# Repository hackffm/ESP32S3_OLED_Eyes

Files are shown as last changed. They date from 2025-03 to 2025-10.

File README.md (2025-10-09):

# ESP32S3_OLED_Eyes
Touch-sensitive OLED Eyes for ESP32-S3 modules based on playfultechnology / esp32-eyes. A badge from Hackerspace-FFM.de that shows eye animation and name on the OLED display.

This is a picture of the badge: 
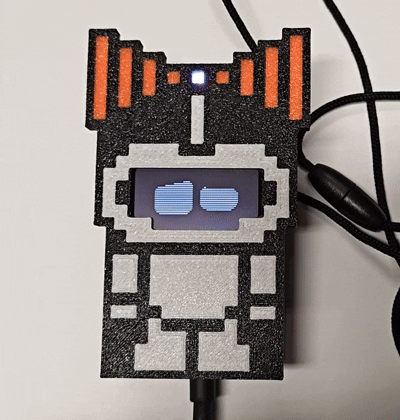
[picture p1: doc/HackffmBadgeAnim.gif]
Badge Animated


More info in [Hackerspace-FFM Wiki](https://www.hackerspace-ffm.de/wiki/index.php?title=Hackerspace-FFM_Badge)

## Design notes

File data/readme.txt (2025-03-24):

This file is in LittleFS of ESP32. More infos about badge:
https://www.hackerspace-ffm.de/wiki/index.php?title=Hackerspace-FFM_Badge

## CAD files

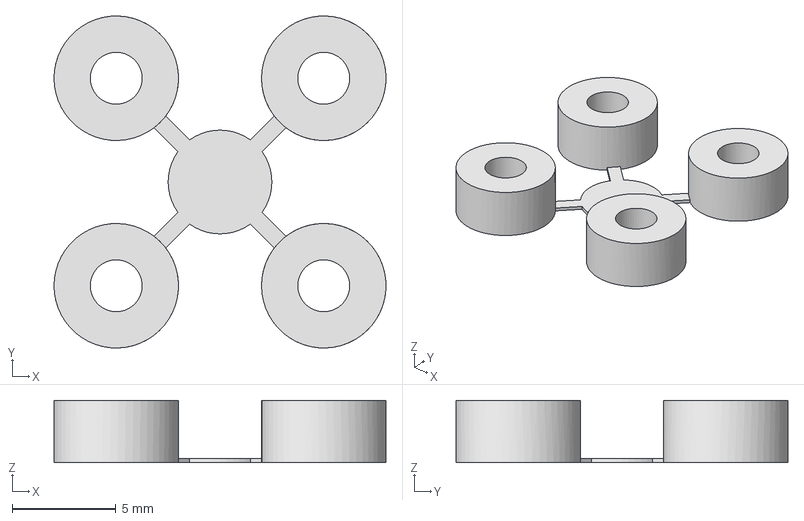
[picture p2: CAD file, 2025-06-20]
hardware/main_mechanics/spacer_3mm.stp
16.0 x 16.0 x 3.00 mm

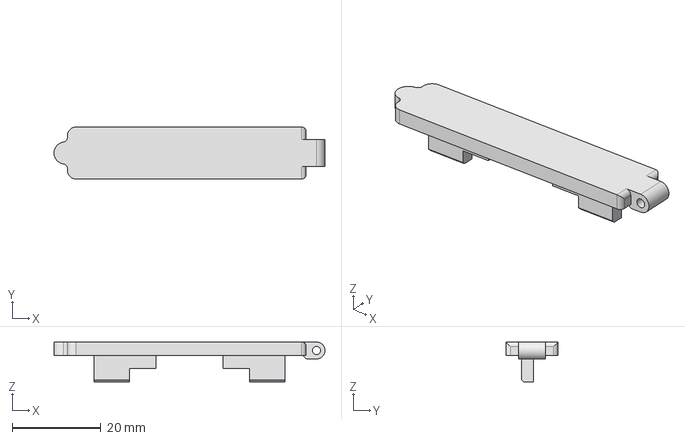
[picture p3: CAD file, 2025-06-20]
hardware/mounting_tools/mcu solder tool lid.stp
61.0 x 11.7 x 9.00 mm

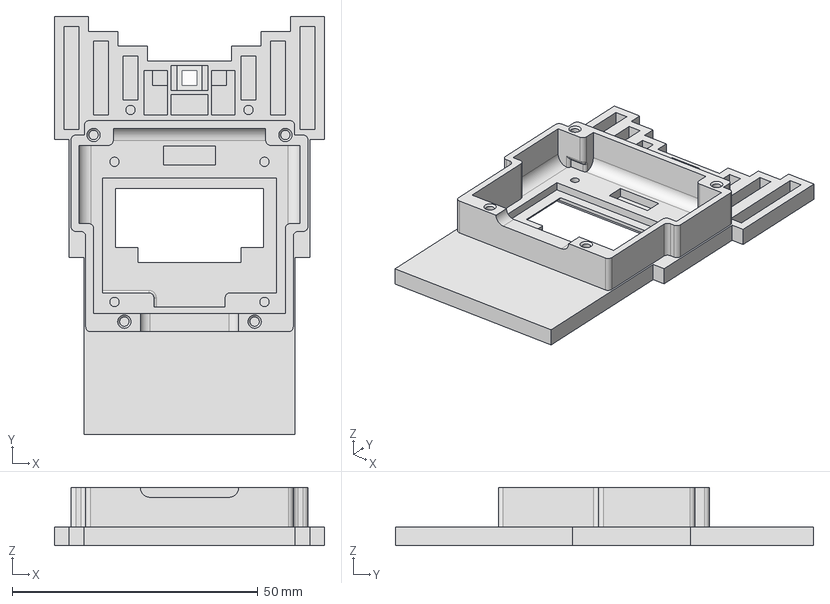
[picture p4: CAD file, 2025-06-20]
hardware/main_mechanics/hackffm-badge.stp
55.0 x 85.0 x 11.8 mm
logo_black
body-new
signal-new
transparent

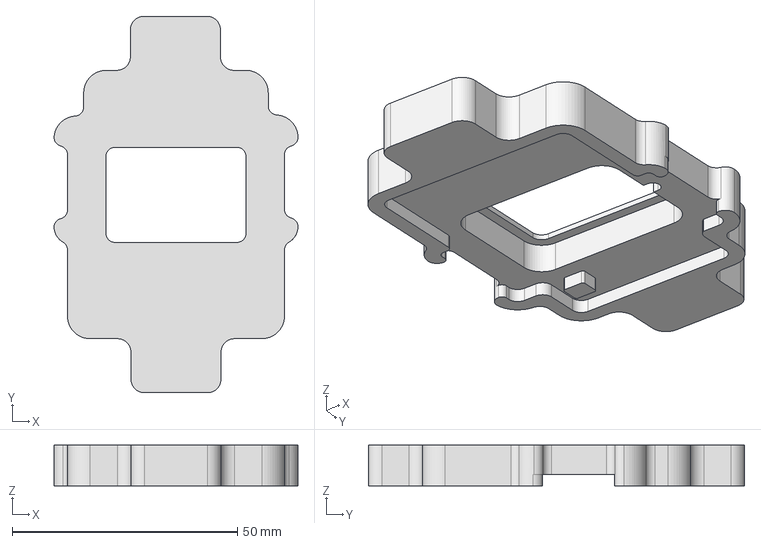
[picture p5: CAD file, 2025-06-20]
hardware/mounting_tools/glue-tool.stp
54.2 x 83.6 x 9.00 mm

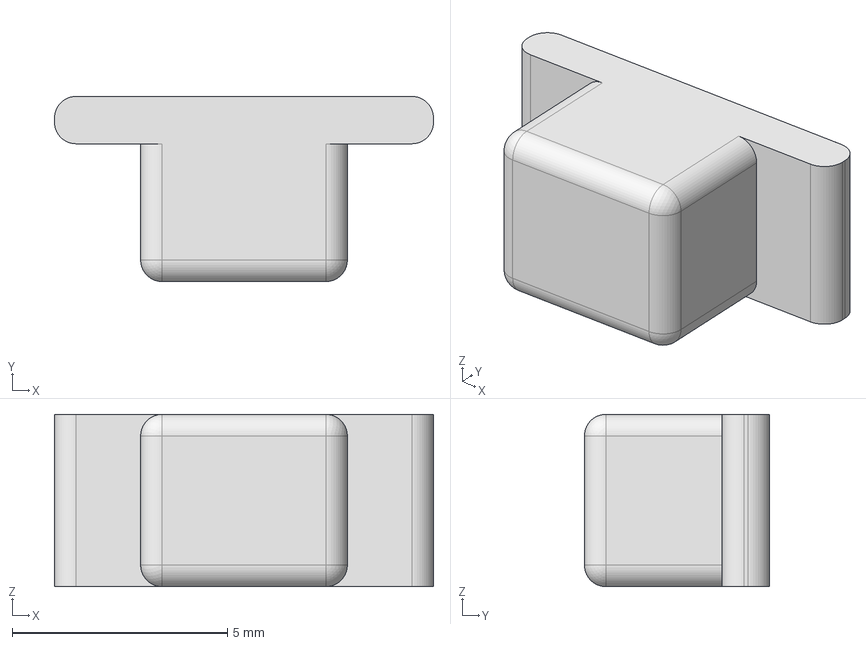
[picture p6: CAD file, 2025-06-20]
hardware/main_mechanics/button-2.stp
8.80 x 4.30 x 4.00 mm

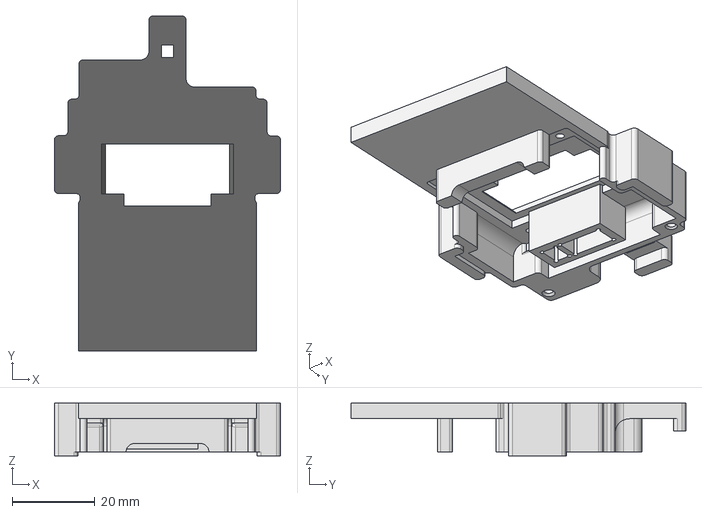
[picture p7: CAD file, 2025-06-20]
hardware/mounting_tools/solder-tool.stp
54.7 x 81.0 x 12.8 mm

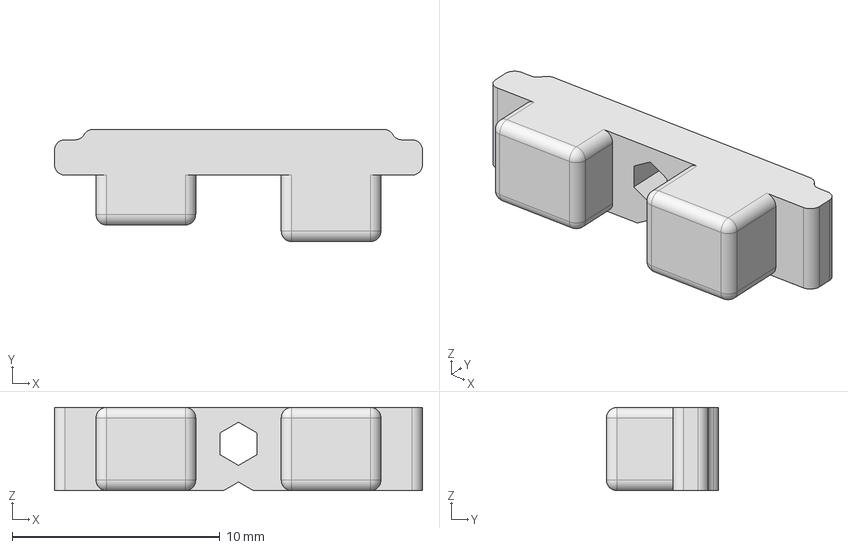
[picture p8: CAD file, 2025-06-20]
hardware/main_mechanics/button.stp
17.7 x 5.40 x 4.00 mm

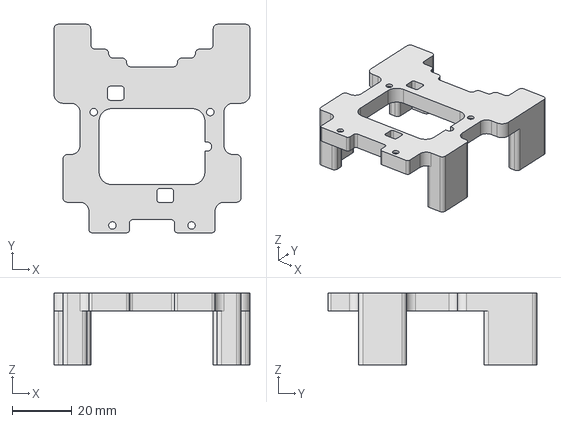
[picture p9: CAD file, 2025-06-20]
hardware/mounting_tools/mounting-tool.stp
65.6 x 69.8 x 24.0 mm

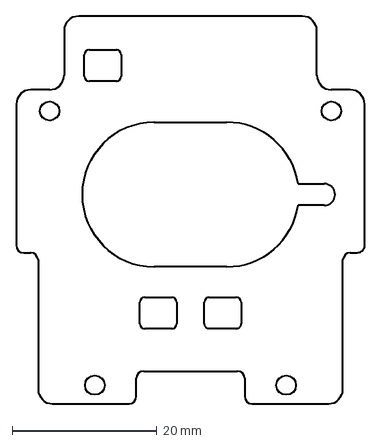
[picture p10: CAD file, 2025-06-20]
hardware/main_mechanics/backside_plexi.dxf
48.2 x 53.6 mm

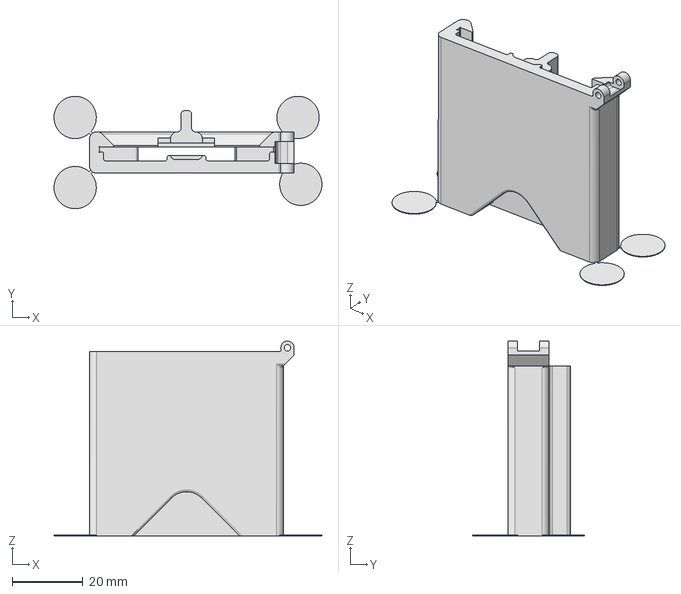
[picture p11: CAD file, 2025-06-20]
hardware/mounting_tools/mcu-solder-tool.stp
76.0 x 31.9 x 55.2 mm

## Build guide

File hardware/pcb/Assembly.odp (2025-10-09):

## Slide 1

1.

Nur bei Audioversion

22k

1uF

R6 wird nicht benötigt

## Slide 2

2.

Digital-transistor

MOSFET P-Ch

Taster

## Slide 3

3.

Nur bei Audioversion

4.7k

1nF

LM4871

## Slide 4

Jumper

Blaues board

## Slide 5

Jumper

Schwarzes board

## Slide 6

Jumper

Schwarzes Board

Jumper

Blaues Board

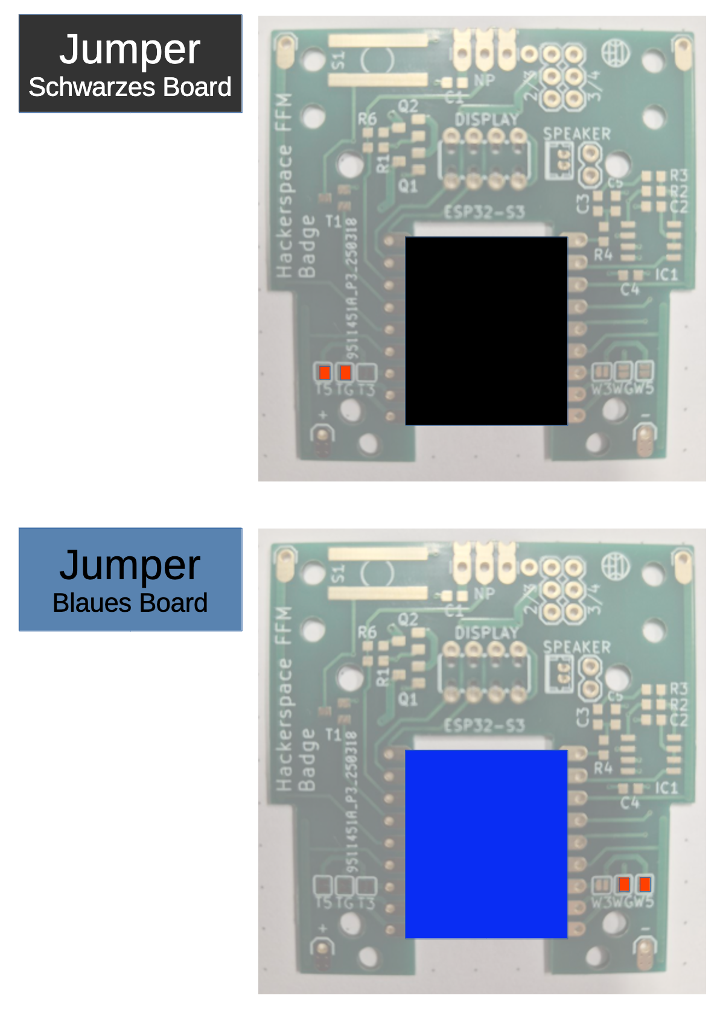
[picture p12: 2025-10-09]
doc/HackFFMEyes Board Jumper Soldering.png

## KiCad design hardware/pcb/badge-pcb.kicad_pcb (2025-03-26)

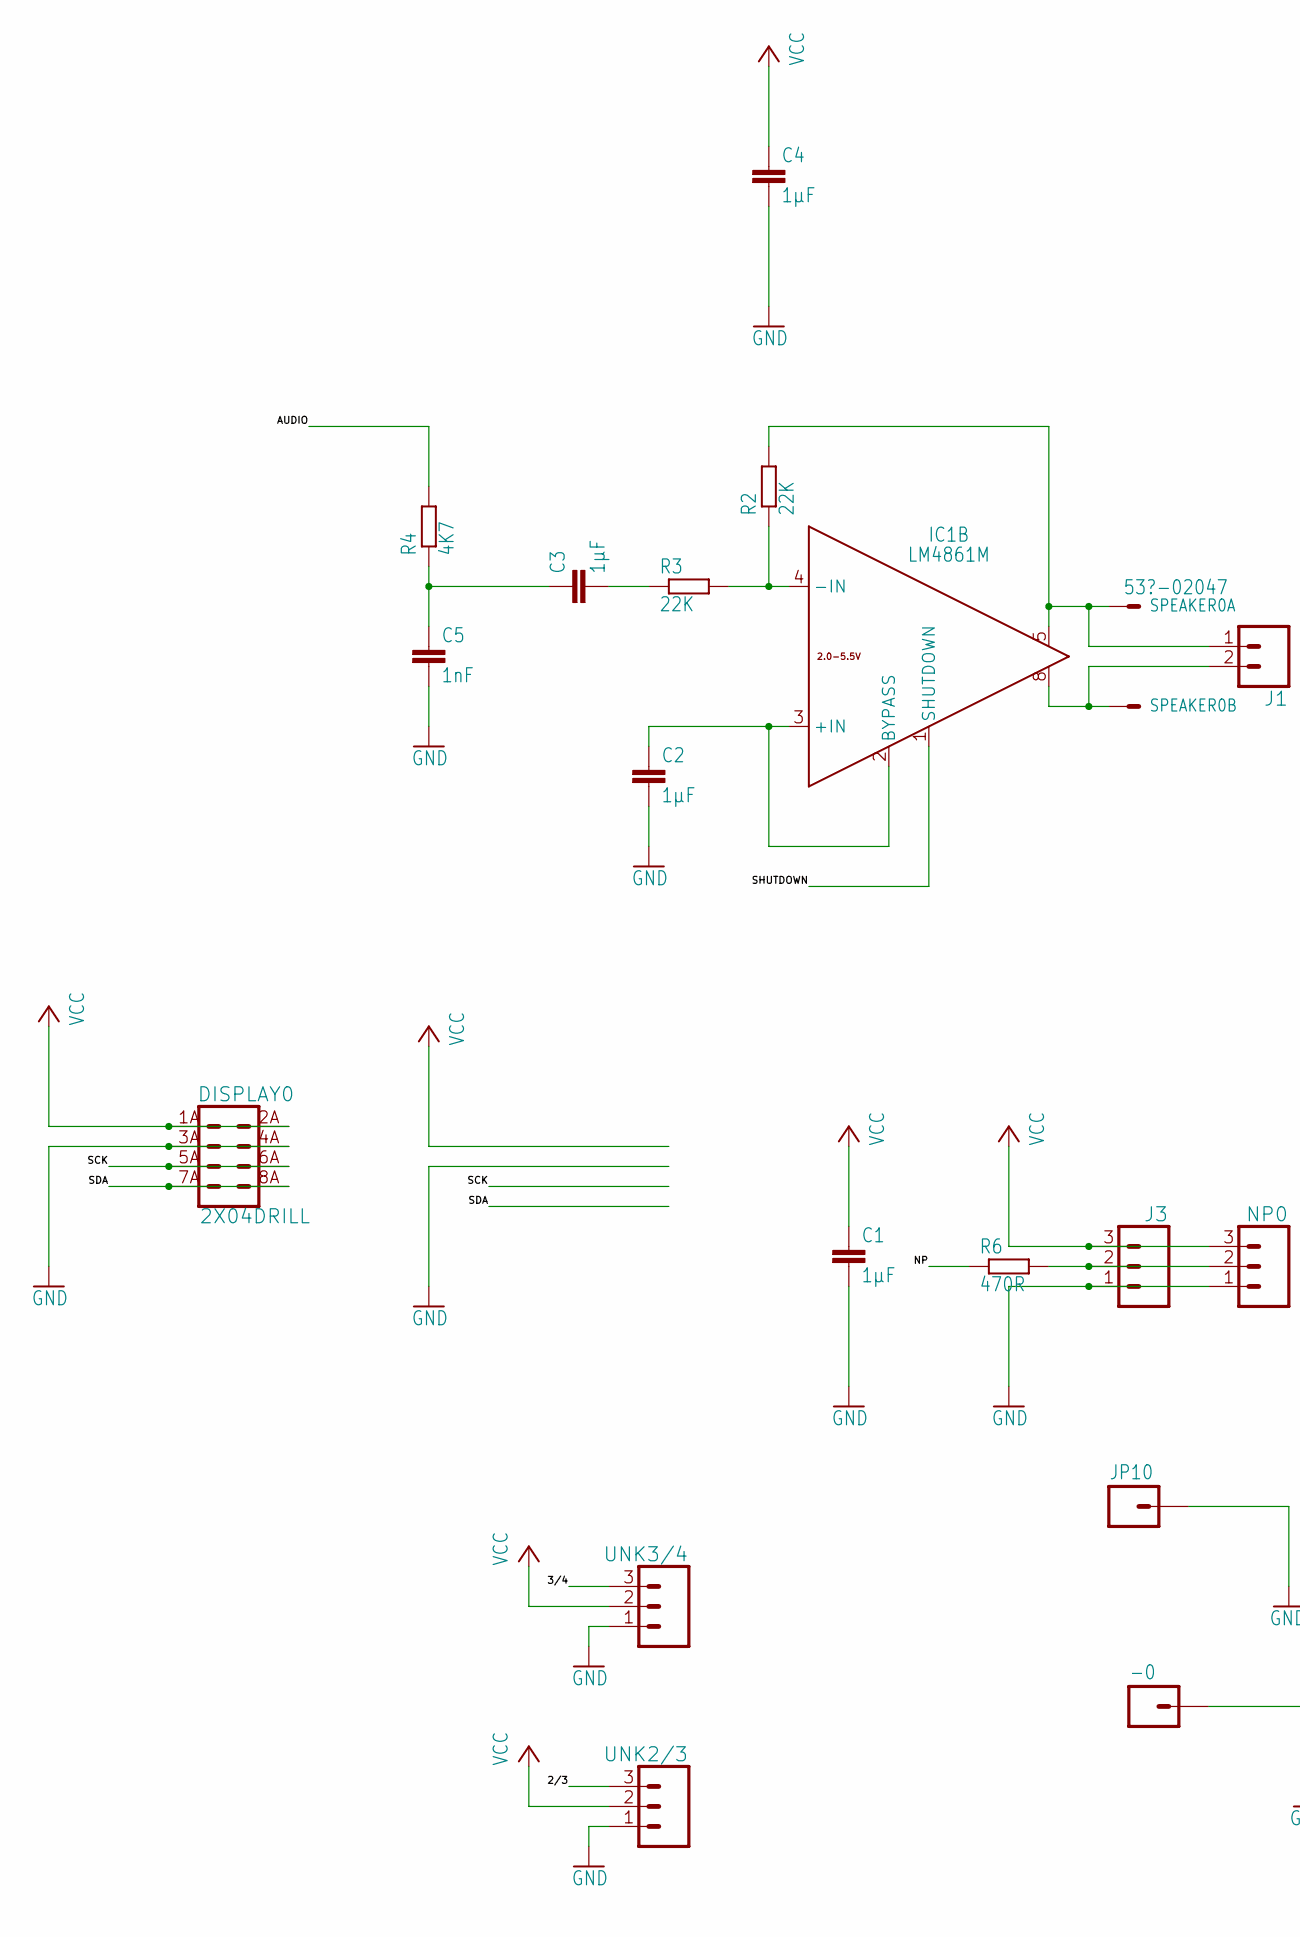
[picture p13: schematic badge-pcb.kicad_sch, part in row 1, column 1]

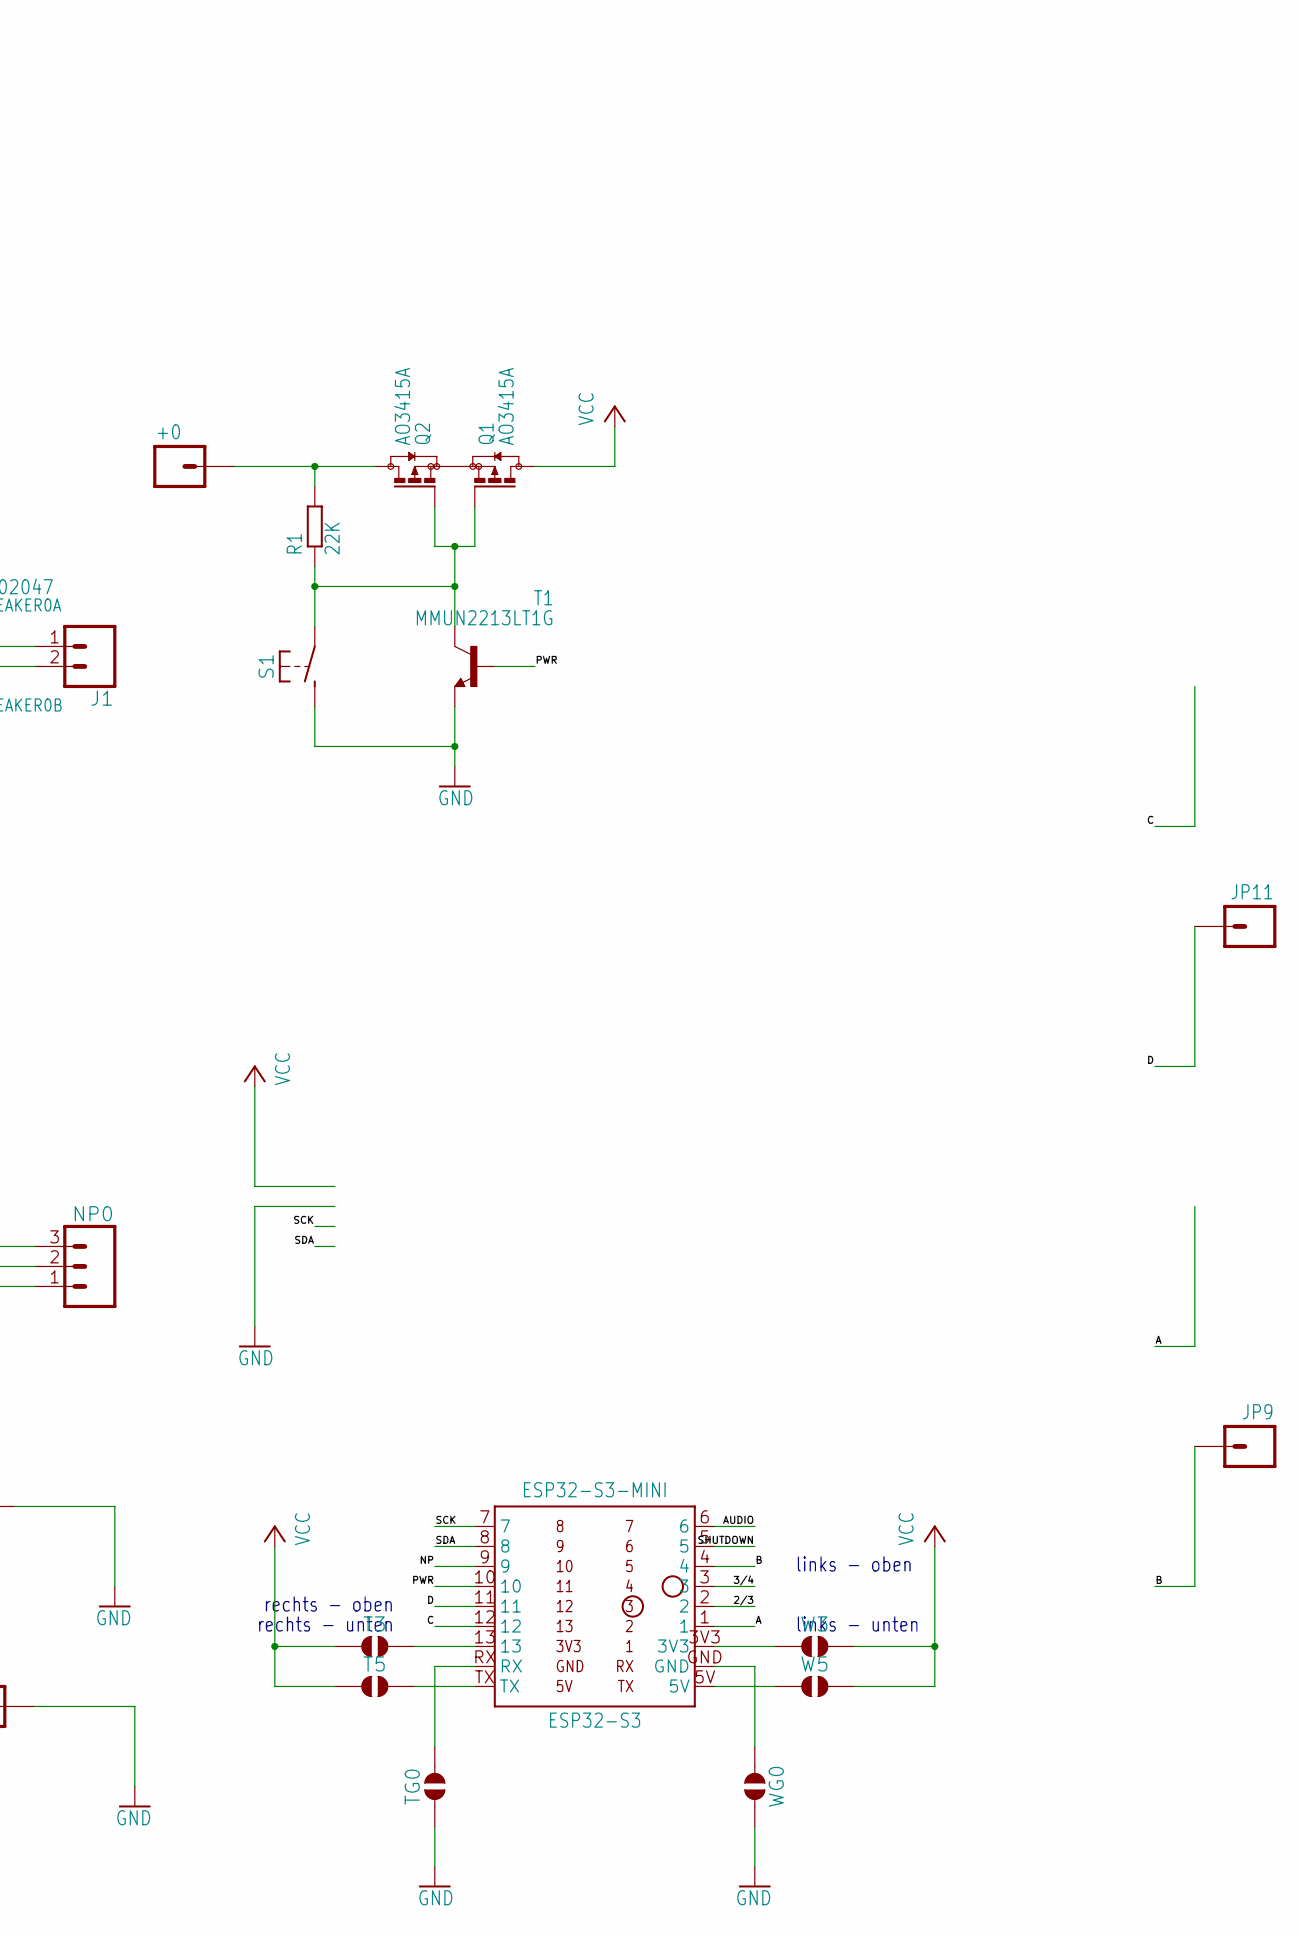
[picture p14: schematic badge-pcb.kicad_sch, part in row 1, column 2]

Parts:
+0: M01OFFSET; 1X01_OFFSET
-0: M01OFFSET; 1X01_OFFSET
C1, C2, C3, C4: 1µF; C0603K
C5: 1nF; C0603K
DISPLAY0: 2X04DRILL; 2X4-DRILL
ESP32-S3: ESP32-S3-MINI
IC1: LM4861M; SOIC8
J1: CONN_02; 1X02
J3: 455-1750-1-ND; 1X03_LONGPADS
JP9, JP11: M01OFFSET; 1X01_OFFSET
JP10: M01PTH; M01_1X01
NP0: 455-1750-1-ND; 1X03_LONGPADS
Q1, Q2: AO3415A; SOT23-3PIN
R1, R2, R3: 22K; R0603
R4: 4K7; R0603
R6: 470R; R0603
S1: MOMENTARY-SWITCH-SPST-21138EM; JTP-1138EM
SPEAKER0: 53?-02047; 53047-02
T1: MMUN2213LT1G; SOT23
T3, T5: JUMPER-SMT_2_NO_SILK; SMT-JUMPER_2_NO_SILK
TG0: JUMPER-SMT_2_NO_SILK; SMT-JUMPER_2_NO_SILK
UNK2/3, UNK3/4: 455-1750-1-ND; 1X03
W3, W5: JUMPER-SMT_2_NO_SILK; SMT-JUMPER_2_NO_SILK
WG0: JUMPER-SMT_2_NO_SILK; SMT-JUMPER_2_NO_SILK

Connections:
2/3: ESP32-S3.2, UNK2/3.3
3/4: ESP32-S3.3, UNK3/4.3
A: ESP32-S3.1
AUDIO: ESP32-S3.6, R4.2
B: ESP32-S3.4, JP9.1
C: ESP32-S3.12
D: ESP32-S3.11, JP11.1
GND: -0.1, C1.2, C2.2, C4.2, C5.2, DISPLAY0.3A (3), DISPLAY0.4A (4), IC1.7 (GND), J3.1, JP10.1, NP0.1, S1.3, S1.4 (3), T1.2 (E), TG0.1, UNK2/3.1, UNK3/4.1, WG0.1
unnamed: ESP32-S3.3V3, W3.2
unnamed: ESP32-S3.13, T3.2
unnamed: ESP32-S3.RX, TG0.2
unnamed: ESP32-S3.GND, WG0.2
unnamed: Q1.2 (S), Q2.2 (S)
unnamed: ESP32-S3.5V, W5.2
unnamed: +0.1, Q2.3 (D), R1.2
unnamed: Q1.1 (G), Q2.1 (G), R1.1, S1.1, S1.2 (1), T1.3 (C)
unnamed: IC1.8 (VO2), J1.2, SPEAKER0.2
unnamed: ESP32-S3.TX, T5.1
unnamed: IC1.5 (VO1), J1.1, R2.2, SPEAKER0.1
unnamed: IC1.4 (-IN), R2.1, R3.2
unnamed: C2.1, IC1.2 (BYPASS), IC1.3 (+IN)
unnamed: C3.2, R3.1
unnamed: C3.1, C5.1, R4.1
unnamed: J3.2, NP0.2, R6.2
NP: ESP32-S3.9, R6.1
PWR: ESP32-S3.10, T1.1 (B)
SCK: DISPLAY0.5A (5), DISPLAY0.6A (6), ESP32-S3.7
SDA: DISPLAY0.7A (7), DISPLAY0.8A (8), ESP32-S3.8
SHUTDOWN: ESP32-S3.5, IC1.1 (SHUTDOWN)
VCC: C1.1, C4.1, DISPLAY0.1A (1), DISPLAY0.2A (2), IC1.6 (VCC), J3.3, NP0.3, Q1.3 (D), T3.1, T5.2, UNK2/3.2, UNK3/4.2, W3.1, W5.1

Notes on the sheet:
rechts - unten
links - unten
links - oben
rechts - oben

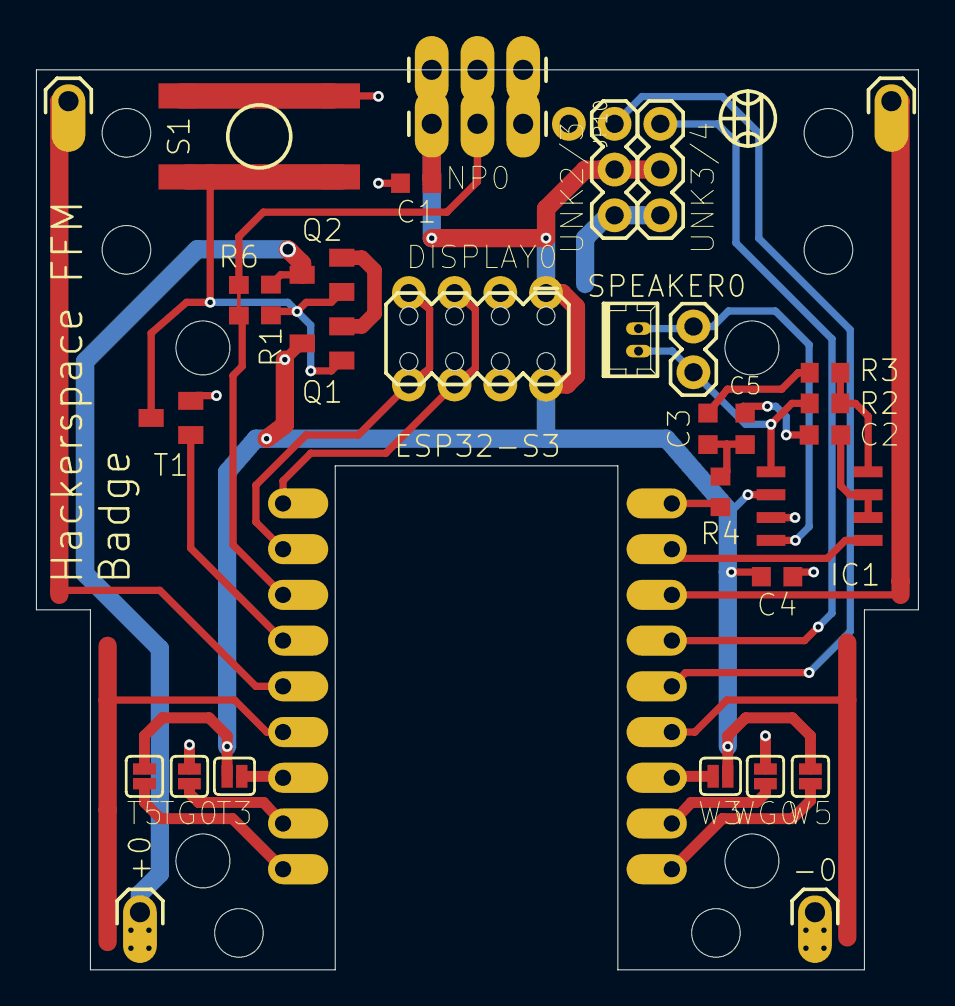
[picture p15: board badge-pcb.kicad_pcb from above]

Board: 2 copper layers, 49.0 x 50.0 mm, 44 parts (0 on the bottom side), 28 nets.

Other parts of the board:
UNK_HOLE_0: dummyfp0
UNK_HOLE_1: dummyfp1
UNK_HOLE_2: dummyfp2
UNK_HOLE_3: dummyfp3
UNK_HOLE_4: dummyfp4
UNK_HOLE_5: dummyfp5
UNK_HOLE_6: dummyfp6
UNK_HOLE_7: dummyfp7
UNK_HOLE_8: dummyfp8
UNK_HOLE_9: dummyfp9

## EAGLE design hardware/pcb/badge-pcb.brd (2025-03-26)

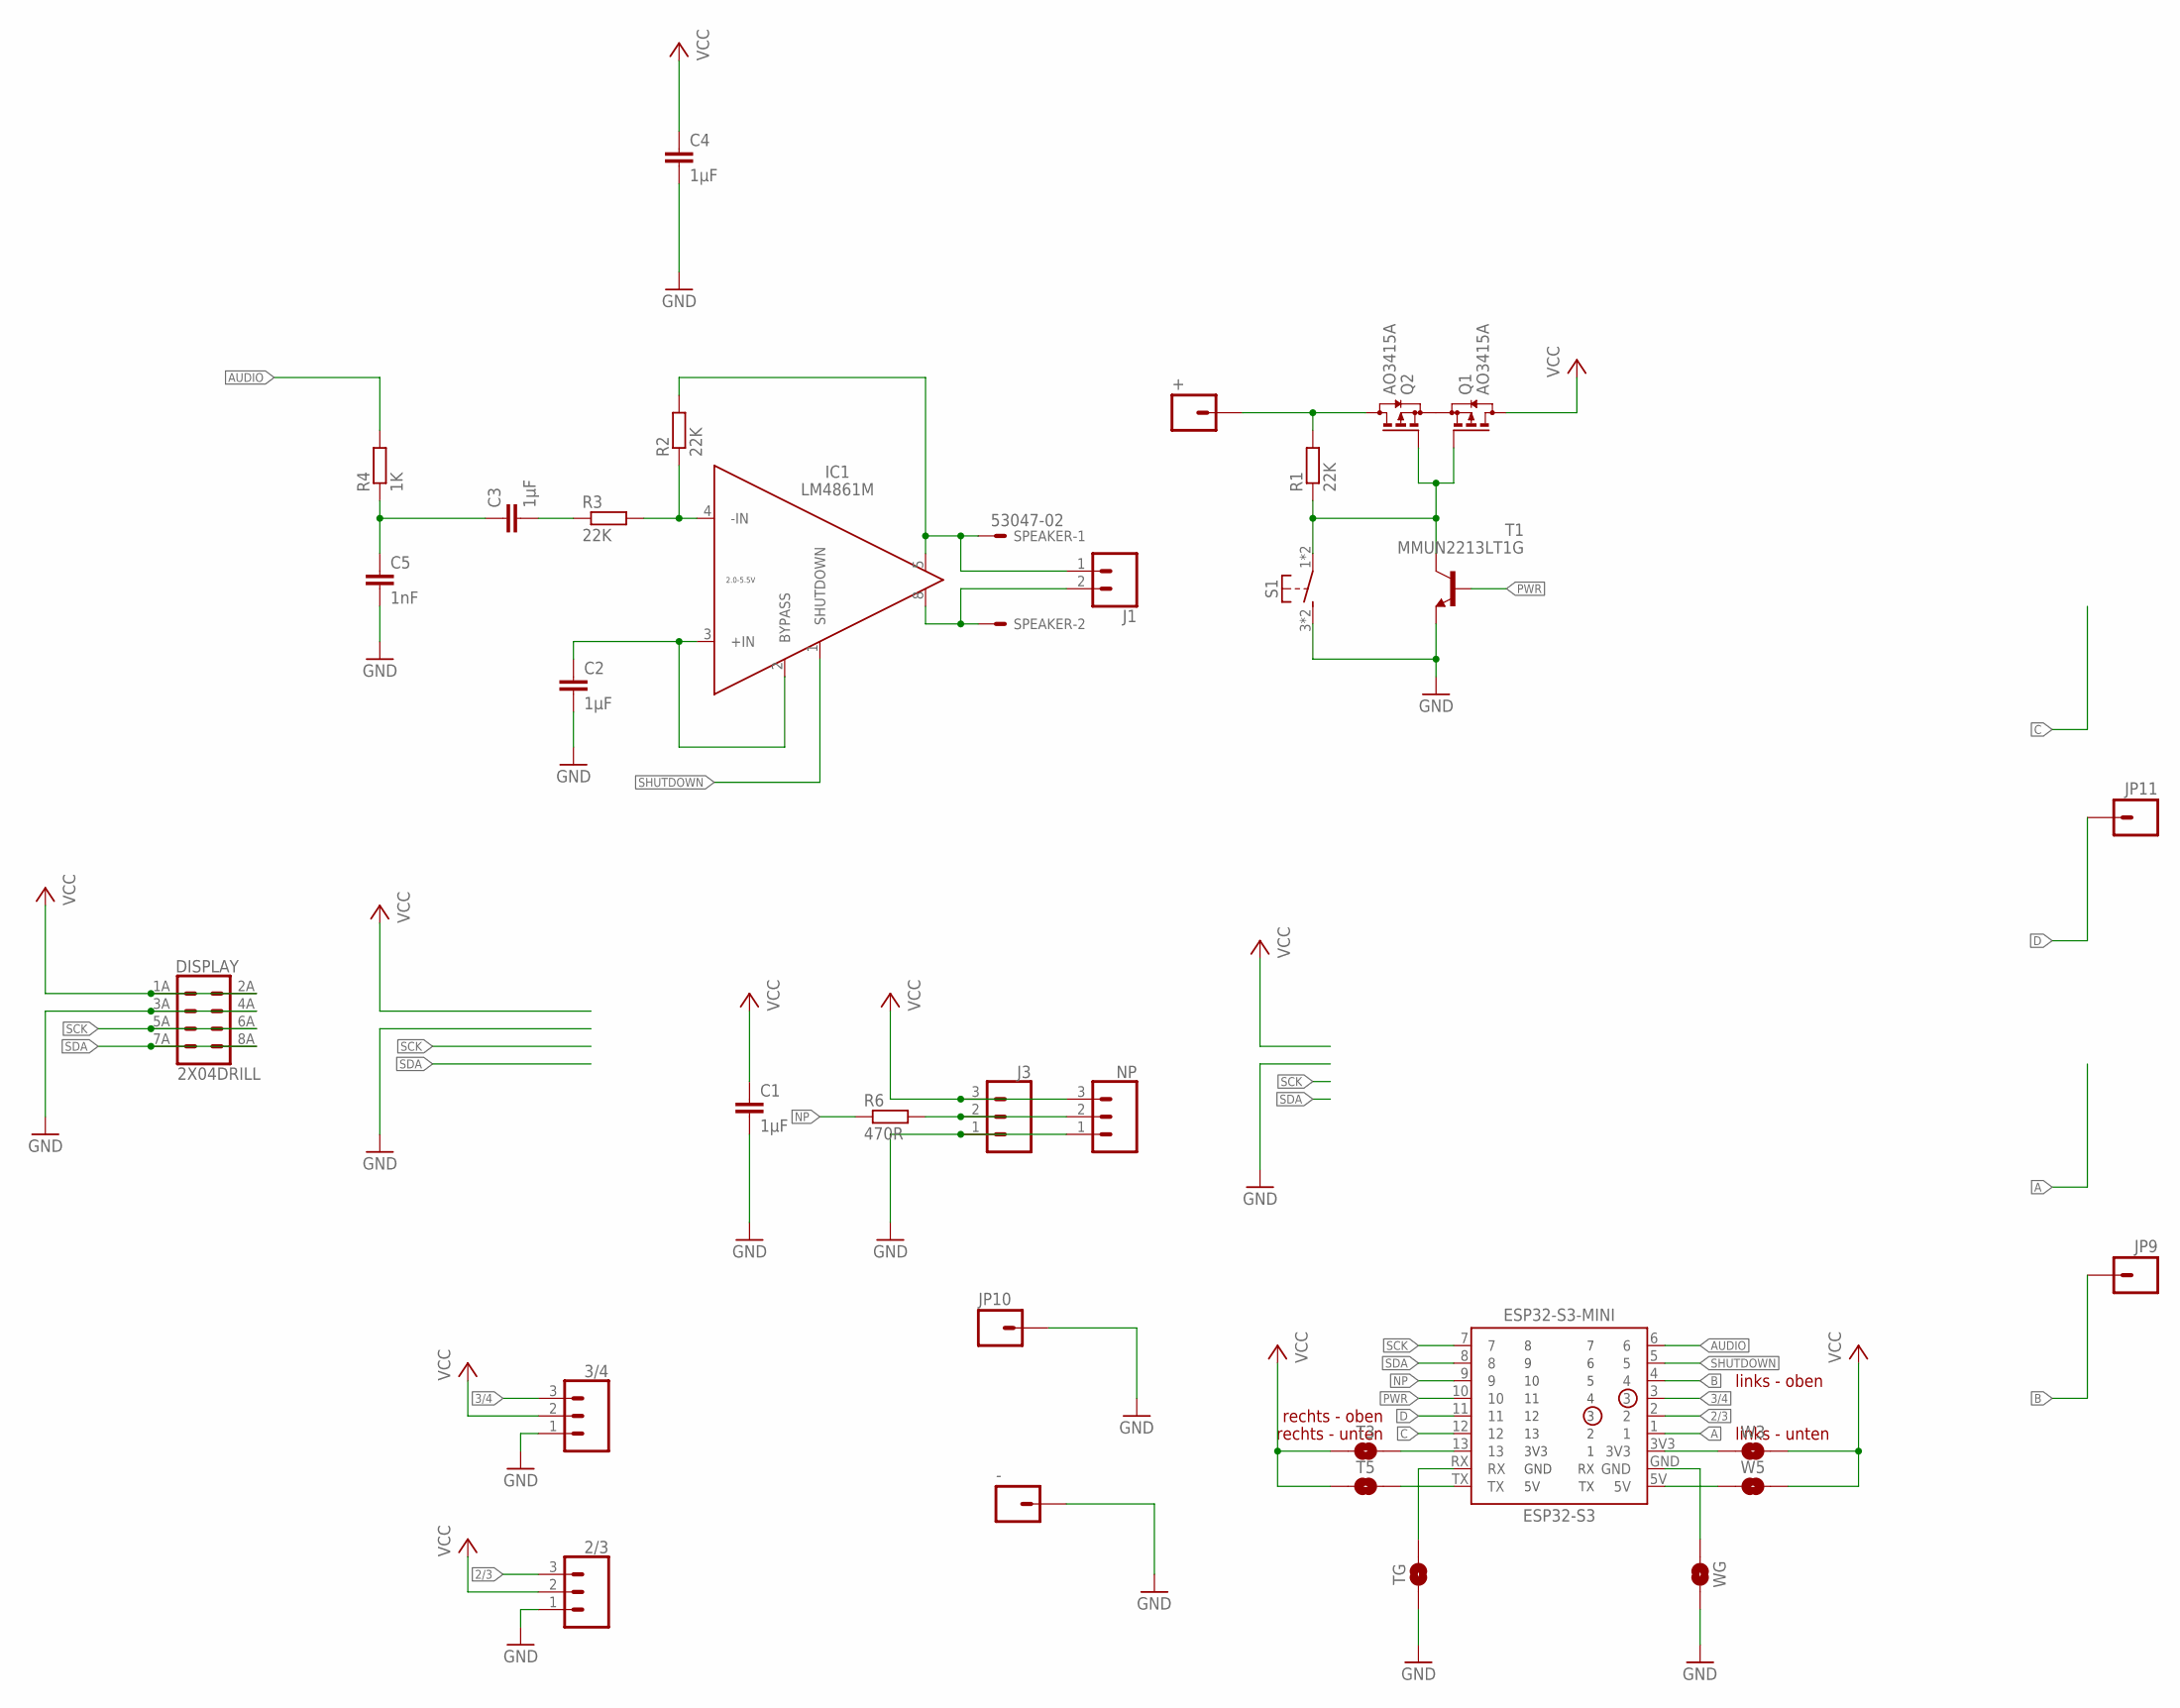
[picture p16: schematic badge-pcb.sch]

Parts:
2/3, 3/4: 455-1750-1-ND; 1X03
+: M01OFFSET; 1X01_OFFSET
-: M01OFFSET; 1X01_OFFSET
C1, C2, C3, C4: 1µF; C0603K
C5: 1nF; C0603K
DISPLAY: 2X04DRILL; 2X4-DRILL
ESP32-S3: ESP32-S3-MINI
IC1: LM4861M; SOIC8
J1: CONN_02; 1X02
J3: 455-1750-1-ND; 1X03_LONGPADS
JP9, JP11: M01OFFSET; 1X01_OFFSET
JP10: M01PTH; M01_1X01
NP: 455-1750-1-ND; 1X03_LONGPADS
Q1, Q2: AO3415A; SOT23-3PIN
R1, R2, R3: 22K; R0603
R4: 1K; R0603
R6: 470R; R0603
S1: MOMENTARY-SWITCH-SPST-21138EM; JTP-1138EM
SPEAKER: 53047-02
T1: MMUN2213LT1G; SOT23
T3, T5: JUMPER-SMT_2_NO_SILK; SMT-JUMPER_2_NO_SILK
TG: JUMPER-SMT_2_NO_SILK; SMT-JUMPER_2_NO_SILK
W3, W5: JUMPER-SMT_2_NO_SILK; SMT-JUMPER_2_NO_SILK
WG: JUMPER-SMT_2_NO_SILK; SMT-JUMPER_2_NO_SILK

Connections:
2/3: 2/3.3, ESP32-S3.2
3/4: 3/4.3, ESP32-S3.3
A: ESP32-S3.1
AUDIO: ESP32-S3.6, R4.2
B: ESP32-S3.4, JP9.1
C: ESP32-S3.12
D: ESP32-S3.11, JP11.1
GND: 2/3.1, 3/4.1, -.1, C1.2, C2.2, C4.2, C5.2, DISPLAY.3A (3), DISPLAY.4A (4), IC1.7 (GND), J3.1, JP10.1, NP.1, S1.3, S1.4 (3), T1.2 (E), TG.1, WG.1
unnamed: ESP32-S3.3V3, W3.2
unnamed: ESP32-S3.13, T3.2
unnamed: ESP32-S3.RX, TG.2
unnamed: ESP32-S3.GND, WG.2
unnamed: Q1.2 (S), Q2.2 (S)
unnamed: ESP32-S3.5V, W5.2
unnamed: +.1, Q2.3 (D), R1.2
unnamed: Q1.1 (G), Q2.1 (G), R1.1, S1.1, S1.2 (1), T1.3 (C)
unnamed: IC1.8 (VO2), J1.2, SPEAKER.2
unnamed: ESP32-S3.TX, T5.1
unnamed: IC1.5 (VO1), J1.1, R2.2, SPEAKER.1
unnamed: IC1.4 (-IN), R2.1, R3.2
unnamed: C2.1, IC1.2 (BYPASS), IC1.3 (+IN)
unnamed: C3.2, R3.1
unnamed: C3.1, C5.1, R4.1
unnamed: J3.2, NP.2, R6.2
NP: ESP32-S3.9, R6.1
PWR: ESP32-S3.10, T1.1 (B)
SCK: DISPLAY.5A (5), DISPLAY.6A (6), ESP32-S3.7
SDA: DISPLAY.7A (7), DISPLAY.8A (8), ESP32-S3.8
SHUTDOWN: ESP32-S3.5, IC1.1 (SHUTDOWN)
VCC: 2/3.2, 3/4.2, C1.1, C4.1, DISPLAY.1A (1), DISPLAY.2A (2), IC1.6 (VCC), J3.3, NP.3, Q1.3 (D), T3.1, T5.2, W3.1, W5.1

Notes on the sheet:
rechts - oben
rechts - unten
links - oben
links - unten

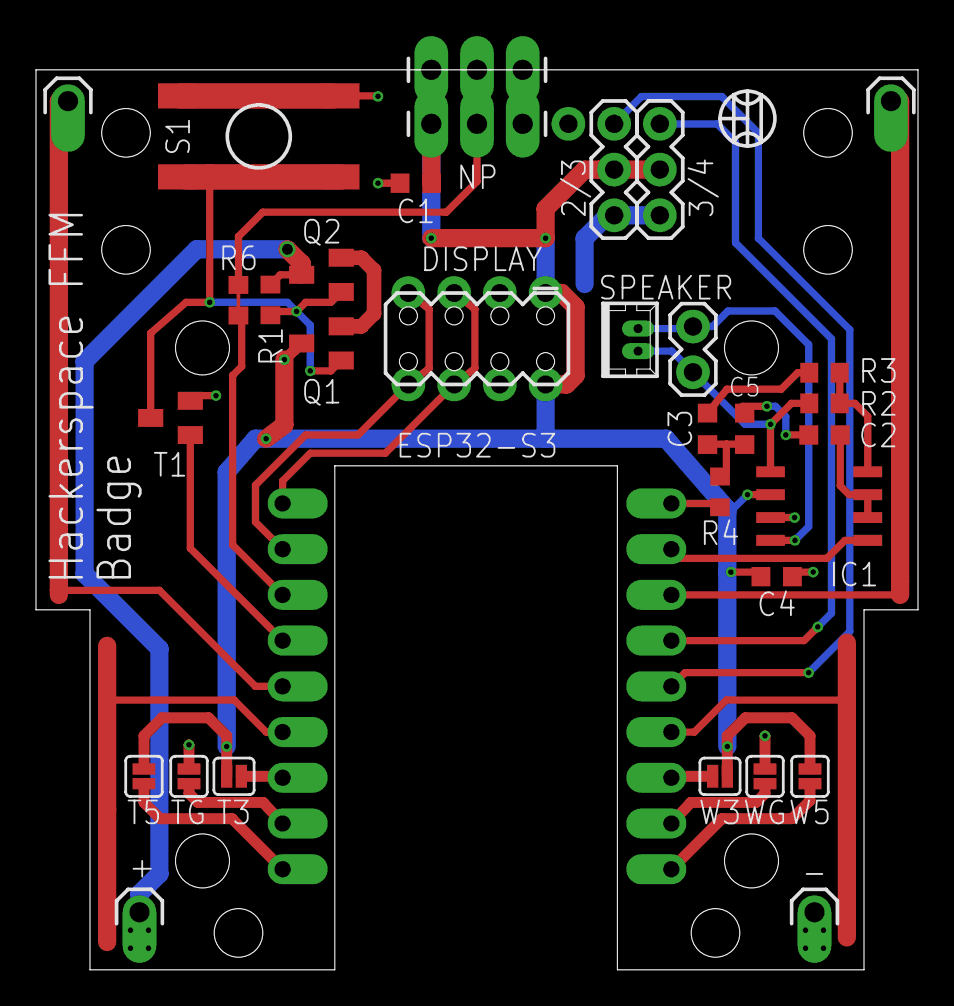
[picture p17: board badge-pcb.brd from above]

Board: 2 copper layers, 49.0 x 50.0 mm, 34 parts (0 on the bottom side), 28 nets.

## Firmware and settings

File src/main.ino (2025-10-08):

/**
   The MIT License (MIT) (but poisoned by GPL in the Face Library)
   Hackerspace-FFM e.V. Badge V1
   2025-04-20 Lutz Lisseck
*/

// Wifi credentials are in a MyCreds.h file that must reside in /<HOME>/.platformio/lib/MyCreds/MyCreds.h
// see attic/MyCreds.h for an example
#if defined __has_include
#  if __has_include (<MyCreds.h>)
#    include <MyCredsHackffm.h>  // Define WIFI_SSID and WIFI_PASSWORD here - see file in Attic for example
#  endif
#endif

#include <hackffm_badge_lib.h>
#include "menu.h"

#include "freertos-all.h"

#include "esp_system.h"
#include "esp_pm.h"

const int EYESTYLES_MAX = 2; // 0 = normal, 1 = also normal, 2 = raster lines
int currentEmotion = -1; // -1 = random behaviour, 0..EMOTIONS_COUNT = specific emotion
int currentEyeStyle = -1; // -2 = raster but changes, -1 = normal but changes, 0 = normal, 1 = also normal, 2 = raster lines
int durationShowEyes = 30000; // 30 seconds
int durationShowName = 5000;
int durationShowLogo = 2000;
int currentShow = 0; // 0 = eyes, 1 = name, 2 = logo
int currentShowDuration = 0;
elapsedMillis durationShowTimer = 0;
bool debugTouch = false;
uint32_t idleTime = 0;



// This sets Arduino Stack Size - comment this line to use default 8K stack size
SET_LOOP_TASK_STACK_SIZE(16*1024); // 16KB

cpp_freertos::Task task1("AntennaLED", 4000, 1, [](){
  // Animate antenna LED
  static uint8_t j = 0;
  static int once = 500;
  j++;
  Badge.setAntennaLED(j%32, j%16, j%20);
  delay(50);
  if(once) {
    once--;
    if(once == 0) {
      Serial.printf(" Task1() - Free Stack Space: %d\n", uxTaskGetStackHighWaterMark(NULL));
    }
  }
});

void setup() {
  HackFFMBadge.begin();

//  if(Badge.filesystem.exists("/startsnd.txt")) Badge.playStartSound();

  Badge.drawBMP("/badge.bmp");
  elapsedMillis logoTimer = 0;
  while(logoTimer < 4000) {
    delay(10);
    if((HackFFMBadge.but0PressedSince() > 1000) /*|| (is_host_usb_device_connected() == true) */ ) {
      #ifdef WIFI_SSID
      LL_Log.println("Long Press");
      Badge.drawString("$!$c$8$+$+$+$+$+$+$+Connecting$nto WiFi..");
      delay(10);
      HackFFMBadge.connectWifi(WIFI_SSID, WIFI_PASSWORD);
      char buf[128]; sprintf(buf, "$!$c$6$+$+$+$+$+$+IP: %s", WiFi.localIP().toString().c_str());
      Badge.drawString(buf);
      Badge.setBoardLED(2, 0, 8); // pink
      delay(8000);
      Badge.but0PressedFor(); // clear button press
      break;
      #endif
    }
  }

  // setup2();
  Badge.playMP3("/boot.mp3");

  task1.Start(1);

  // Cast screen to this channel if file exists and contains the channel number
  Badge.txDisplaydata(Badge.readFile("/scrncast.chn").toInt());
}




// Shows eyes, logo, name and cycles through those
void doShow() {
  static int nameFade = 0;
  // Cycle when currentShowDuration is over
  if(durationShowTimer > currentShowDuration) {
    durationShowTimer = 0;
    currentShow++;
    if(currentShow >= 3) currentShow = 0;
    // set new currentShowDuration
    switch(currentShow) {
      case 0: 
        currentShowDuration = durationShowEyes; 
        if(currentEyeStyle < 0) {
          currentEyeStyle--;
          if(currentEyeStyle < -(EYESTYLES_MAX)) currentEyeStyle = -1; // reset to normal
        }
        break;
      case 1: currentShowDuration = durationShowName; nameFade = 128; break;
      case 2: currentShowDuration = durationShowLogo; break;
    }
  }

  // Renders actual show
  if(currentShowDuration > 0) {
    switch(currentShow) {
      case 0: // eyes, modify style if necessary
        Badge.face().UpdateBuffer(); // ~450us
        if(abs(currentEyeStyle) == 2) {
          // raster lines
          u8g2.setDrawColor(0);
          for(int y = 0; y < 64; y+=2) {
            u8g2.drawHLine(0,y,128);
          }
          u8g2.setDrawColor(1);
        }
        break;
      case 1: // Show user name, if not starting with $ then auto-size font
        u8g2.setDrawColor(1);
        if(Badge.userName[0] == '$') {
          String showuser = "$c$3$+$+$+$+";
          showuser.concat(Badge.userName);
          //showuser.replace(" ", "$n");
          Badge.drawString(showuser.c_str(),0,0,2,true);
        } else { 
          Badge.drawCenteredUTF8Text(Badge.getCleanName(Badge.userName).c_str(),true);
        }
        // Add fading effect
        if(nameFade > 0) {
          u8g2.setDrawColor(0);
          for(int y = 0; y < 64; y+=4) {
            u8g2.drawHLine(0,y,nameFade);
            u8g2.drawHLine(0,y+1,nameFade);
            u8g2.drawHLine(128-nameFade,y+2,nameFade);
            u8g2.drawHLine(128-nameFade,y+3,nameFade);
          }
          u8g2.setDrawColor(1);
          nameFade-=3;
        }
        break;
      case 2: // logo
        Badge.drawBMP("/badge.bmp", true);
        break;        
    }
  }

}


void loop() {

  Badge.update();  // <50us

  // Clear display buffer, paint first layer but dont send it to display
  u8g2.clearBuffer(); // <10us
  
  doShow(); // Paint eyes, name or logo
  
  LL_Log.update(); 

  doMenu(); // Overpaint if Menu is active

  float x = Badge.lastTouchX;
  float y = Badge.lastTouchY;
  x = constrain(x, -2.0, 2.0);
  y = constrain(y, -2.0, 2.0);
  Badge.face().Look.LookAt(-x, -y); 
  
  if(debugTouch) doDebugTouch();

  // Process commands from the command line
  processCommands();
  
  // Write to display
  if(Badge.OledAddress) u8g2.sendBuffer();  

  // Optionally transfer display data to external display (big Hackerspace-FFM mannequin)
  if(Badge.txDisplayChannel > 0) Badge.txDisplaydata(Badge.txDisplayChannel);

  // Idle this way disturbs USB serial connection - reduced CPU frequency instead to 80 Mhz
  if(idleTime > 0) {
    esp_sleep_enable_timer_wakeup(idleTime * 1000);
    esp_light_sleep_start();
  }
}


// Process commands from the command line
void processCommands() {
  if(LL_Log.receiveLineAvailable()) {
    LL_Log.println(LL_Log.receiveLine);

    if(LL_Log.receiveLine[0]=='B') {
      int data;
      if(sscanf(&LL_Log.receiveLine[1],"%d",&data)>=1) {
        LL_Log.printf("Brigthness Data: %d\r\n",  data);
        u8g2.setContrast(data);
      }
    }  
    if(LL_Log.receiveLine[0]=='W') {
      int addr, data;
      if(sscanf(&LL_Log.receiveLine[1],"%d %d",&addr, &data)>=2) {
        LL_Log.printf("Addr: %d, Data: %d\r\n", addr, data);
        Badge.face().Behavior.SetEmotion((eEmotions)addr /* moods[addr] */, (float)(data % 21) / 20.0 );
      }
    }
    if(LL_Log.receiveLine[0]=='n') {
      char data[128];
      if(sscanf(&LL_Log.receiveLine[1],"%127[^\n]",&data)>=1) {
        strcpy(Badge.userName, data);
        LL_Log.printf("Bade name: %s\r\n",  Badge.userName);
        Badge.writeFile("/name.txt", Badge.userName);
        Badge.genDoorName();
        Badge.saveKey();
      } else {
        LL_Log.printf("Bade name: %s\r\n",  Badge.userName);
      }

      durationShowTimer = 0;
      currentShowDuration = durationShowName;
      currentShow = 1; // show name
    } 
    if(LL_Log.receiveLine[0]=='P') {
      char data[128];
      if(sscanf(&LL_Log.receiveLine[1],"%127[^\n]",&data)>=1) {
        bool gkstat = Badge.genKey(data);
        if(gkstat) {
          LL_Log.printf("Key set to: %s\r\n",  data);
          Badge.saveKey();
        } else {
          LL_Log.printf("GenKey failed: %s\r\n",  data);
        }
      } else {
        char buf[70];
        bytes2hex(Badge.door_pubkey, 32, buf);
        LL_Log.printf("Public key: %s\r\n",  buf);
      }

    } 
    if(LL_Log.receiveLine[0]=='i') {
      int data;
      if(sscanf(&LL_Log.receiveLine[1],"%d",&data)>=1) {
        //LL_Log.printf("Idle time: %d\r\n",  data);
        //idleTime = data;
        esp_pm_config_t pm_config = {
          .max_freq_mhz = 240,
          .min_freq_mhz = 80,
          .light_sleep_enable = false
        };
        
        switch(data) {
          case 0: pm_config.max_freq_mhz = 240; break;
          case 1: pm_config.max_freq_mhz = 160; break;
          case 2: pm_config.max_freq_mhz = 80; break;
          case 3: pm_config.max_freq_mhz = 40; break;
          case 4: pm_config.max_freq_mhz = 20; break;
          case 5: pm_config.max_freq_mhz = 10; break;
        }
        ESP_ERROR_CHECK(esp_pm_configure(&pm_config));
      } else {
        LL_Log.printf(" Loop() - Free Stack Space: %d\n", uxTaskGetStackHighWaterMark(NULL));
        LL_Log.printf(" CPU_Freq: %d MHz\r\n", ESP.getCpuFreqMHz());
      }
     // LL_Log.printf(" u8g2: %d \r\n", u8g2.getBufferSize());
     // Badge.txDisplaydata(13);
    }
    if(LL_Log.receiveLine[0]=='D') {
      char data[128];
      if(sscanf(&LL_Log.receiveLine[1],"%127[^\n]",&data)>=1) {
        String del_name = "/" + String(data);
        LL_Log.printf("Delete file: %s\r\n",  del_name.c_str());
        if(Badge.filesystem.exists(del_name.c_str())) {
          if(Badge.filesystem.remove(del_name.c_str())) {
            LL_Log.printf("File %s deleted\r\n", del_name.c_str());
          } else {
            LL_Log.printf("File %s delete failed\r\n", del_name.c_str());
          }
         } else {
          LL_Log.printf("File %s not found\r\n", del_name.c_str());
        }
      }
    }
    if(LL_Log.receiveLine[0]=='a') {

      Badge.drawCenteredUTF8Text(&LL_Log.receiveLine[1]);
      delay(10000);
    }
    if(LL_Log.receiveLine[0]=='R') {
      LL_Log.println("Peer Radar on.");
      Badge.peerRadarTxInterval = 1000; 
      Badge.peerRadarRxDuration = 20000;
    }
  }
}

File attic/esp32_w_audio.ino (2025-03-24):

/**
   The MIT License (MIT)
*/

#include "hackffm_badge_lib.h"

#include <MyCredsHackffm.h>      // Define WIFI_SSID and WIFI_PASSWORD here
#include <elapsedMillis.h>
#include <WiFi.h>
#include <WiFiClient.h>
#include <ArduinoOTA.h>

#include "LL_Lib.h"
#include "helper.h" 

//#define WAV_AUDIO_ACTIVE 1

#ifdef WAV_AUDIO_ACTIVE
  #include "AudioTools.h"
  //#include "knghtsng.h"
  //#include "alice.h"
  //#include "walle1.h"
  #include "happy.h"


  //Data Flow: MemoryStream -> EncodedAudioStream  -> PWMAudioOutput
  //Use 8000 for alice_wav and 11025 for knghtsng_wav
  AudioInfo info(11025, 1, 16);

  MemoryStream wav((const uint8_t*)happytree, wav_len);
  //MemoryStream wav(knghtsng_wav, knghtsng_wav_len);
  //MemoryStream wav(alice_wav, alice_wav_len);
  PWMAudioOutput pwm;          // PWM output 
  //EncodedAudioStream out(&pwm, new WAVDecoder()); // Decoder stream
  StreamCopy copier(pwm, wav, 60000);    // copy in to out

  Task task("mp3-copy", 10000, 1, 0);
#endif

const char* hostname = "esp32-oled";
 
void setup() {
  HackFFMBadge.begin();

  LL_Log.begin(115200, 2222); // Serial baud, TCP Port

  //connectWifi(WIFI_SSID, WIFI_PASSWORD, hostname); 
  //while(1) delay(1);

  // Assign a weight to each emotion
  Badge.face().Behavior.SetEmotion(eEmotions::Normal, 0.5);
  Badge.face().Behavior.SetEmotion(eEmotions::Happy, 0.3);
  Badge.face().Behavior.SetEmotion(eEmotions::Glee, 0.2);
  // Automatically switch between behaviours (selecting new behaviour randomly based on the weight assigned to each emotion)
  Badge.face().RandomBehavior = true;

  // Automatically blink
  Badge.face().RandomBlink = true;
  // Set blink rate
  Badge.face().Blink.Timer.SetIntervalMillis(4000);

  // Automatically choose a new random direction to look
  Badge.face().RandomLook = true;

 
  #ifdef WAV_AUDIO_ACTIVE
  // AudioToolsLogger.begin(Serial, AudioToolsLogLevel::Info);
    Badge.setPowerAudio(true);
    wav.begin();
    // out.begin();

    auto config = pwm.defaultConfig();
    config.copyFrom(info);
    config.start_pin = HackFFMBadge.pinAudio;
    pwm.begin(config);

    // task.begin([](){copier.copy();});
  #endif

}


void loop() {
  static elapsedMillis pressedTime = 0;
  static bool lastButState = true;
  static elapsedMillis blinkTimer = 0;

  Badge.update();

  u8g2.clearBuffer();
  Badge.face().UpdateBuffer();
  u8g2.sendBuffer();


  LL_Log.update(); 

  
  if(blinkTimer > 100) {
    static int emo = 0;
    blinkTimer = 0;

    #if 0
    if(lastButState != digitalRead(0)) {
      lastButState = digitalRead(0);
      if(lastButState == 0) {
        pressedTime = 0;
      } else {
        if(pressedTime > 1000) {
          LL_Log.println("Long Press");
          delay(1000);
          HackFFMBadge.powerOff();
        } else {
          LL_Log.println("Short Press");
          emo++;
          if(emo>=EMOTIONS_COUNT) emo = 0;
          face->Behavior.GoToEmotion((eEmotions)emo);
        }
      }
    }
    if(digitalRead(0)==0) {
      LL_Log.println("Push");
      emo++;
      if(emo>=EMOTIONS_COUNT) emo = 0;
      face->Behavior.GoToEmotion((eEmotions)emo);
    }
    //int logbox_y = u8g2.getDisplayHeight() - (U8LOG_HEIGHT * U8LOG_FONT_Y) - 3;
    /*
    u8g2.setFont(U8LOG_FONT);
    u8g2.setFontPosTop();
    u8g2.setFontMode(0);
    u8g2.setDrawColor(1);
    u8g2.drawBox(0,logbox_y,u8g2.getDisplayWidth(),u8g2.getDisplayHeight()-logbox_y);
    u8g2.setDrawColor(0);
    u8g2.drawBox(1,logbox_y+1,u8g2.getDisplayWidth()-2,u8g2.getDisplayHeight()-(logbox_y+2));
    //u8g2.drawHLine(stillAlive % u8g2.getDisplayWidth(),logbox_y,4); // interrupt line to show beeing alive
    u8g2.setDrawColor(1);
    u8g2.drawLog(2,logbox_y+1,u8g2log);
    */
    //u8g2.sendBuffer();
    //LL_Log.printf("Touch %d %d %d %d\r\n", touchRead(14), touchRead(12), touchRead(15), touchRead(2));

    #endif
    if(HackFFMBadge.isNewTouchDataAvailable()) {
      float x = (float)HackFFMBadge.touch[0].getTouchValue() / 100.0 - (float)HackFFMBadge.touch[1].getTouchValue() / 100.0;
      float y = (float)HackFFMBadge.touch[2].getTouchValue() / 100.0 - (float)HackFFMBadge.touch[3].getTouchValue() / 100.0;
   //   LL_Log.printf("Touch %d %d %d %d %f:%f\r\n", HackFFMBadge.touch[0].getLastTouchValue(), 
   //     HackFFMBadge.touch[1].getLastTouchValue(), HackFFMBadge.touch[2].getLastTouchValue(), 
   //     HackFFMBadge.touch[3].getLastTouchValue(),x,y);
      Badge.face().Look.LookAt(x, y); 
    }


    static uint8_t j = 0;
    j++;
    for (int i = 0; i < 2; i++) {
    //  HackFFMBadge.setAntennaLED( HackFFMBadge.freenoveAntennaLED->Wheel((i * 256 / 2 + j) & 255)); // crash...
    }
    Badge.setAntennaLED(j%32, j%16, j%20);
  }


  if(LL_Log.receiveLineAvailable()) {
    LL_Log.println(LL_Log.receiveLine);
    if(LL_Log.receiveLine[0]=='d') {

    }  
    if(LL_Log.receiveLine[0]=='w') {
      int addr, data;
      if(sscanf(&LL_Log.receiveLine[1],"%d %d",&addr, &data)>=2) {
        LL_Log.printf("Addr: %d, Data: %d\r\n", addr, data);
        Badge.face().Behavior.SetEmotion((eEmotions)addr /* moods[addr] */, (float)(data % 21) / 20.0 );
      }
    }
  }

  ArduinoOTA.handle();
  if(OTAinProgress == false) {
  //  face->Update();
  } 
  

  #ifdef WAV_AUDIO_ACTIVE
    if (wav) {
      copier.copy();
    } else if(0) {
      // after we are done we just print some info form the wav file
      auto info = pwm.audioInfo();
    //  LOGI("The audio rate from the wav file is %d", info.sample_rate);
    //  LOGI("The channels from the wav file is %d", info.channels);

      // restart from the beginning
      Serial.println("Restarting...");
      //delay(3000);
      face->Wait(3000);
      //out.begin();   // indicate that we process the WAV header
      wav.begin();       // reset actual position to 0
      pwm.begin();       // reset counters 
    }
  #endif
}

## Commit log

2025-03-24 Big cleanup #1
    [custom_partitions.csv]
2025-03-26 Clean 3
    [badge-pcb.kicad_pcb, badge-pcb.kicad_sch]
2025-03-28 in terminal naming mode switch to screen mode name
2025-06-20 Big cleanup
    [backside_plexi.dxf, badge-pcb.brd, badge-pcb.kicad_pcb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]
2025-10-06 FW Update possible by holding button when no display and blinking red/blue.

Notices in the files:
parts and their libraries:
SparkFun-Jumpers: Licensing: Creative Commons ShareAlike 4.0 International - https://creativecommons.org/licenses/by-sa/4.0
